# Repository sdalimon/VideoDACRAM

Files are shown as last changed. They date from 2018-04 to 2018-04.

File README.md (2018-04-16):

This is an adapter to add 512kB of SRAM and a simple video output to the Lattice MachXO3 starter board.

My original experiments used internal block RAM and a simple 2 resistor output that used the 75 ohm input of the TV.

As I got the resolution up the block RAM ran out, so this includes an SRAM.

The video out is now buffered and provides a proper 75 ohm output with an RCA socket.

Connect it to the J8 heade rof the dev board.

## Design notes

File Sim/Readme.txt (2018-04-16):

Resistor_Values.sci - SciLab program to brtue force the resistor values
ResistorCalcs.xlsx - Excel sheet to play with resistor values
Video_Out.asc - LTSpice simualation of output circuit

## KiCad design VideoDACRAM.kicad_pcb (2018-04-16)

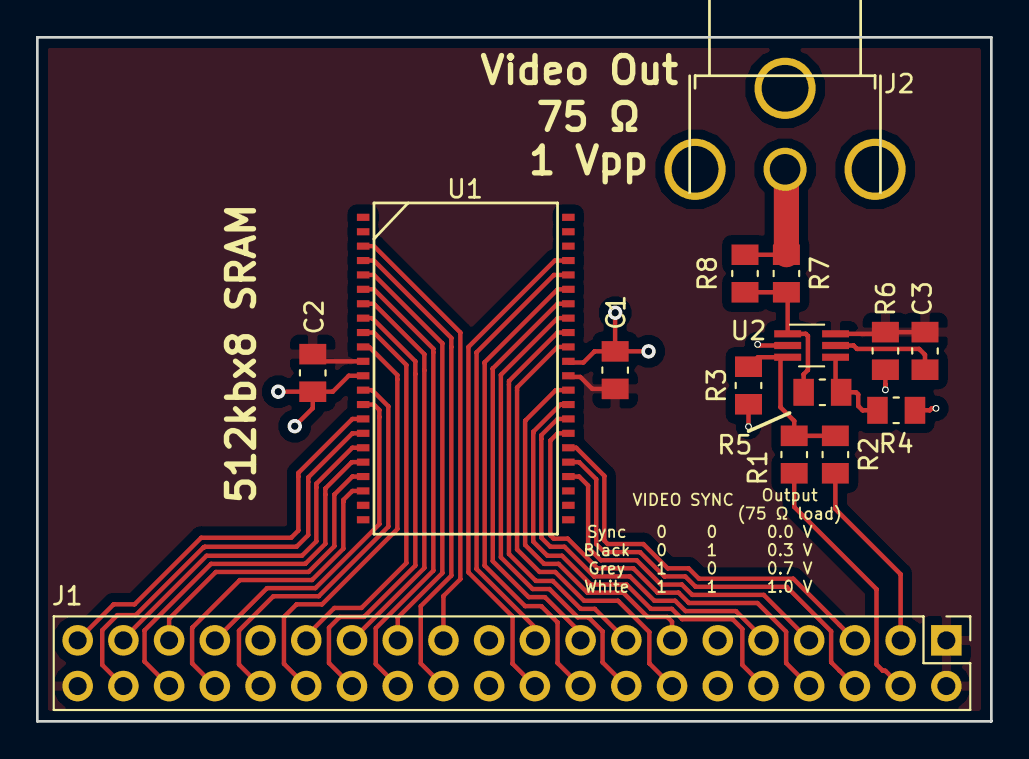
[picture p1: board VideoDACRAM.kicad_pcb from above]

Board: 2 copper layers, 53.0 x 38.0 mm, 15 parts (0 on the bottom side), 39 nets.

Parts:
C1, C2, C3: 100n; C_0805_2012Metric_Pad1.15x1.50mm_HandSolder
J1: Conn_01x40; PinHeader_2x20_P2.54mm_Vertical
J2: RCJ-014
R1: 4k7; R_0805_2012Metric_Pad1.15x1.50mm_HandSolder
R2: 12k; R_0805_2012Metric_Pad1.15x1.50mm_HandSolder
R3: 1k5; R_0805_2012Metric_Pad1.15x1.50mm_HandSolder
R4, R5: 680; R_0805_2012Metric_Pad1.15x1.50mm_HandSolder
R6: 1k; R_0805_2012Metric_Pad1.15x1.50mm_HandSolder
R7: NI; R_0805_2012Metric_Pad1.15x1.50mm_HandSolder
R8: 75; R_0805_2012Metric_Pad1.15x1.50mm_HandSolder
U1: CY7C1049GN30-xxZSXI; TSOP 44 18.8x10.1x0.8
U2: LMH6601; SOT-363_SC-70-6_Handsoldering

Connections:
/SRAM_A0: J1.23, U1.3
/SRAM_A1: J1.24, U1.4
/SRAM_A2: J1.25, U1.5
/SRAM_A3: J1.26, U1.6
/SRAM_A4: J1.27, U1.7
/SRAM_A5: J1.38, U1.16
/SRAM_A6: J1.37, U1.17
/SRAM_A7: J1.36, U1.18
/SRAM_A8: J1.35, U1.19
/SRAM_A9: J1.34, U1.20
/SRAM_A10: J1.7, U1.26
/SRAM_A11: J1.6, U1.27
/SRAM_A12: J1.5, U1.28
/SRAM_A13: J1.8, U1.29
/SRAM_A14: J1.9, U1.30
/SRAM_A15: J1.17, U1.38
/SRAM_A16: J1.18, U1.39
/SRAM_A17: J1.19, U1.40
/SRAM_A18: J1.20, U1.41
/SRAM_D0: J1.29, U1.9
/SRAM_D1: J1.30, U1.10
/SRAM_D2: J1.32, U1.13
/SRAM_D3: J1.33, U1.14
/SRAM_D4: J1.10, U1.31
/SRAM_D5: J1.13, U1.32
/SRAM_D6: J1.14, U1.35
/SRAM_D7: J1.15, U1.36
/SRAM_~CE: J1.28, U1.8
/SRAM_~OE: J1.16, U1.37
/SRAM_~WE: J1.39, U1.15
/SYNC: J1.3, R2.2
/VIDEO: J1.4, R1.2
GND: C1.2, C2.2, C3.2, J1.11, J1.12, J1.21, J1.22, J1.31, J2.2, R3.1, R4.1, U1.12, U1.34, U2.2
unnamed: J2.1, R7.1, R8.1
unnamed: R1.1, R2.1, R3.2, U2.3
unnamed: R4.2, R5.2, U2.4
unnamed: R5.1, R7.2, R8.2, U2.1
unnamed: R6.1, U2.5
VDD: C1.1, C2.1, C3.1, J1.1, J1.2, J1.40, R6.2, U1.11, U1.33, U2.6
